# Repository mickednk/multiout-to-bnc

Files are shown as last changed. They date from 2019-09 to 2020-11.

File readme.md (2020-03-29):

# Multiout to BNC
The Console to BNC is a small project I put together to solve my snakepit of cables behind my consoles and Extron Crosspoint.
this PCB board is the main part of the project and doesnt need to be used with BNC connectors, you can use it in combination with a SCART connector or regular RCA connectors. the purpose of the PCB is to move the components closer to the console.

## SNES to BNC
This PCB is designed to be used with a NTSC SNES console, it will work with both a US SNES and a Japanese Super Famicom.
It will also work with a NESRGB modified NES if it uses an multiout connector like the AV Famicom does.
It might be compatible with other multiout consoles but it is designed with the NTSC SNES in mind.

### Parts needed
| Mouser part number | Quantity  | Description | Designation |
| :--- | :---: | :--- | :--- |
| 81-GRM31CR60J227ME1K  | 3 | 220uF capacitory 1206 package | C1, C2, C3  |

## Gamecube to BNC
This PCB is designed to be used with a PAL Gamecube ONLY.
It will not work with an NTSC Gamecube because they don't output RGB and I am pretty sure it would damage the monitor that you connect to.

### Parts needed
| Mouser part number | Quantity  | Description | Designation |
| :--- | :---: | :--- | :--- |
| 81-GRM31CR60J227ME1K  | 3 | 220uF capacitor 1206 package  | C1, C2, C3 |
| 581-06036C104KAT2A | 2 | 0.1uF capacitor 603 package | C4, C5 |
| 71-CRCW0603680KFKEAC  | 1 | 680KOhm resistor 603 package  | R1 |
| 71-CRCW060375R0FKEAC  | 1 | 75Ohm resistor 603 package | R2 |
| 926-LM1881MX/NOPB | 1 | LM1881 Sync seperator circuit | U2 |

## PS2 to BNC
This PCB is designed to be used with Playstation 2 ONLY, it wont work with PS1 because it needs caps on the RGB lines to be compatible with PS1.

### Parts needed
| Mouser part number | Quantity  | Description | Designation |
| :--- | :---: | :--- | :--- |
| 581-06036C104KAT2A | 2 | 0.1uF capacitor 603 package | C1, C2 |
| 71-CRCW0603680KFKEAC  | 1 | 680KOhm resistor 603 package  | R1 |
| 926-LM1881MX/NOPB | 1 | LM1881 Sync seperator circuit | U1 |

## Connectors
### Nintendo consoles
The PCB is designed to use the knock off multiout connector that can be found at Console5.com (https://console5.com/store/nintendo-snes-super-famicom-n64-av-multi-out-plug-for-custom-rgb-cables-repair.html)
I have seen it on Aliexpress as well so it shouldn't be to difficult to find.

### Playstation consoles
The PCB is designed to use the knock off multiout connector that can be found at Console5.com (https://console5.com/store/sony-playstation-1-2-ps1-ps2-av-multi-out-plug-for-custom-rgb-cables-repair.html)
I have seen it on Aliexpress as well so it shouldn't be to difficult to find.

# Contribute to the project
I am not an electrical engineer so I have probably made tons of mistakes when routing and such, there is probably even more errors on the Gamecube one. With that said you are welcome to contribute by doing pull requests to this repository. I have taken this project as far as I need it but I can see how someone might want to build one for the PAL SNES or the N64.

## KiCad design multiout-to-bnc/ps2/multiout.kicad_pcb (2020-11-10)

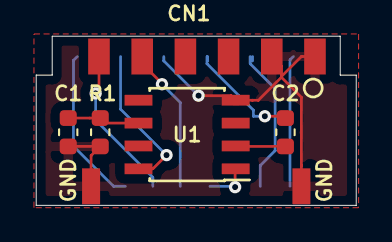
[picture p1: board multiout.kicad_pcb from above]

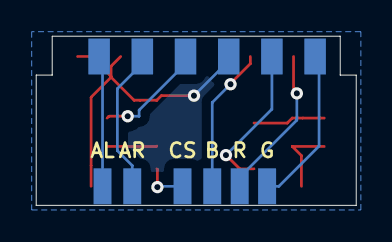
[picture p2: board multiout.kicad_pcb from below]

Board: 2 copper layers, 17.8 x 9.4 mm, 13 parts (6 on the bottom side), 11 nets.

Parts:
AL: L; WIREPAD
AR: R; WIREPAD
B: B; WIREPAD
C1, C2: 0.1uF; C_0603_1608Metric
CN1: AVCONNECTOR
CS: CS; WIREPAD
G: G; WIREPAD
GND: GND; WIREPAD
GND#2: GND; WIREPAD
R: R; WIREPAD
R1: 680k; R_0603_1608Metric
U1: LM1881; SOIC-8_3.9x4.9mm_P1.27mm

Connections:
GND: C1.1, CN1.1, CN1.3, CN1.8, GND.1, GND#2.1, R1.1, U1.4
unnamed: C1.2, R1.2, U1.6
unnamed: C2.1, CN1.6
unnamed: C2.2, U1.2
unnamed: AL.1, CN1.2
unnamed: AR.1, CN1.4
unnamed: B.1, CN1.9
unnamed: CN1.11, R.1
unnamed: CN1.12, G.1
unnamed: CS.1, U1.1
VCC: CN1.10, U1.8

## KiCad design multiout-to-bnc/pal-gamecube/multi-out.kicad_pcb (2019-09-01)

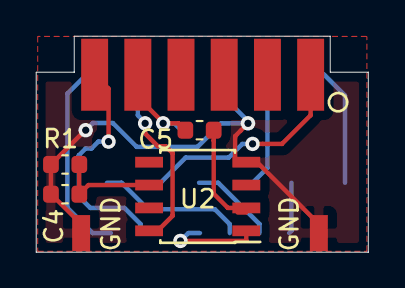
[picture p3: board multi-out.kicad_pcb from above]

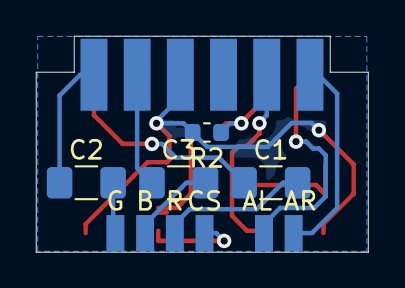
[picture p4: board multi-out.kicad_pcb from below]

Board: 2 copper layers, 18.4 x 12.0 mm, 17 parts (10 on the bottom side), 14 nets.

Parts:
AL: L; WIREPAD
AR: R; WIREPAD
B: B; WIREPAD
C1, C2, C3: 220uF; C_1206_3216Metric_Pad1.42x1.75mm_HandSolder
C4, C5: 0.1uF; C_0603_1608Metric
CS: CS; WIREPAD
G: G; WIREPAD
GND: GND; WIREPAD
GND#2: GND; WIREPAD
R: R; WIREPAD
R1: 680k; R_0603_1608Metric
R2: 75k; R_0603_1608Metric
U1: AV-CONNECTOR; AVCON
U2: LM1881; SOIC-8_3.9x4.9mm_P1.27mm

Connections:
GND: C4.1, GND.1, GND#2.1, R1.1, R2.2, U1.5, U1.6, U2.4
unnamed: C1.1, U1.1
unnamed: C1.2, R.1
unnamed: C2.1, U1.2
unnamed: C2.2, G.1
unnamed: C3.1, U1.4
unnamed: B.1, C3.2
unnamed: C4.2, R1.2, U2.6
unnamed: C5.1, R2.1, U1.9
unnamed: C5.2, U2.2
unnamed: CS.1, U2.1
unnamed: AR.1, U1.12
unnamed: AL.1, U1.11
unnamed: U1.10, U2.8

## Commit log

2019-05-01 Add project for SNES PCB
    This one will also work with NESRGB modified NES.
    [multi-out.kicad_pcb, multi-out.sch]
2019-05-01 Add project for PAL Gamecube PCB
    [multi-out.kicad_pcb, multi-out.sch]
2019-09-01 Add 75 Ohm resistor between composite line and ground
    [multi-out.kicad_pcb, multi-out.sch]
2020-01-31 Add readme with information and instructions on the PCB
2020-02-16 Add new project for PS2 to BNC
    [multiout.kicad_pcb, multiout.sch]
2020-02-16 Add schematic symbol for the multiout connector
2020-02-19 Add footprint for multiout connector
2020-02-19 Add schematic layout of the board
    [multiout.sch]
2020-02-19 Add footprint of the wirepad
2020-02-19 Assign footprint to schema symbols
    [multiout.sch]
2020-02-19 Add design rules and layer rules
    [multiout.kicad_pcb]
2020-02-19 Add outline to edge cut layer
    [multiout.kicad_pcb]
2020-02-19 Add routes to pcb
    [multiout.kicad_pcb]
2020-03-22 Update footprint of connector
2020-03-22 Reroute after design changes to connector
    [multiout.kicad_pcb]
2020-11-10 Corrected placement of edge connector.
    [multiout.kicad_pcb]
